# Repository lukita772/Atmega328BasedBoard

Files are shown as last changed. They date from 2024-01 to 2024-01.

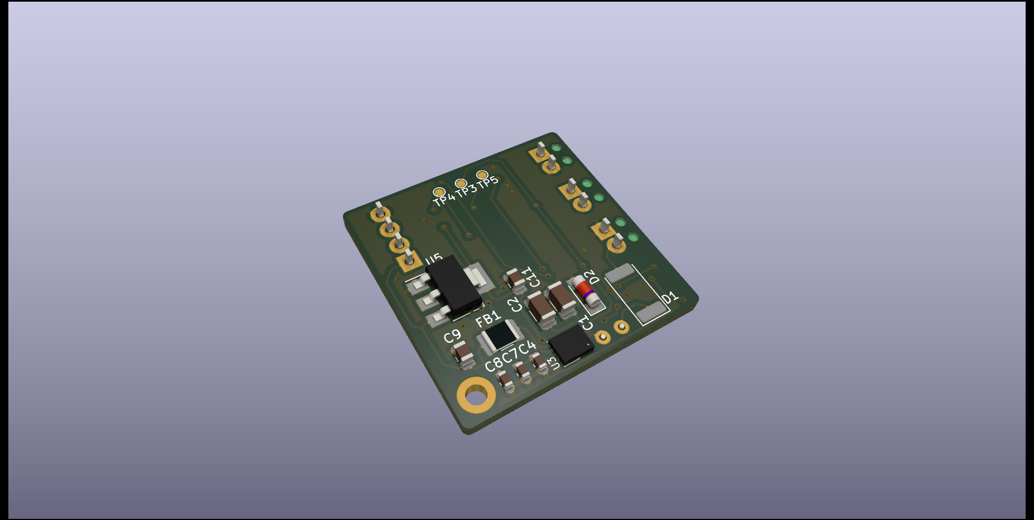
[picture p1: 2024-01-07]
Schematics&Renders/Hibot_agostiniLuca_boardBack.png

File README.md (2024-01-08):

# Atmega328BasedBoard
Hibot_agostiniLuca_boardFront
Hibot_agostiniLuca_boardBack
[Schematic.pdf](https://github.com/lukita772/Atmega328BasedBoard/files/13856203/Schematic.pdf)

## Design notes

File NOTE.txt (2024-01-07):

For time reasons, i couldnt finish to choose the calculus for the right protections in the input circuit

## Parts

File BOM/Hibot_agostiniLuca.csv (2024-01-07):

Id | Designator | Package | Quantity | Designation | Supplier and ref
1 | U6 | TRANS_IRL100HS121 | 1 | IRLHS6342TRPBF
2 | R7,R4,R8,R5 | R_0603_1608Metric | 4 | 5k 5%
3 | R2 | R_0603_1608Metric | 1 | 1Meg 1%
4 | F1 | C_Disc_D3.0mm_W1.6mm_P2.50mm | 1 | Polyfuse_Small
5 | R3 | R_0603_1608Metric | 1 | 10k 5%
6 | U2 | LGA-12_2x2mm_P0.5mm | 1 | LSM303C
7 | R6 | R_0603_1608Metric | 1 | 200m 1%
8 | C10 | C_0805_2012Metric | 1 | 10u 16v X7R
9 | L1 | L_0201_0603Metric | 1 | 10uH
10 | Y1 | Crystal_SMD_Abracon_ABM10-4Pin_2.5x2.0mm | 1 | RH100-8.000-8-2020-TR
11 | C14,C13 | C_0603_1608Metric | 2 | 22pF 16v X7R
12 | C3 | C_0805_2012Metric | 1 | 220nF 16v X7R
13 | J3 | TerminalBlock_Phoenix_MPT-0,5-2-2.54_1x02_P2.54mm_Horizontal | 1 | Load
14 | J2 | TerminalBlock_Phoenix_MPT-0,5-4-2.54_1x04_P2.54mm_Horizontal | 1 | SerialOutput
15 | D3 | D_0805_2012Metric | 1 | 1N4007FL
16 | R1 | R_0603_1608Metric | 1 | 1k 5%
17 | J4 | TerminalBlock_Phoenix_MPT-0,5-2-2.54_1x02_P2.54mm_Horizontal | 1 | Output2
18 | U4 | QFN-32-1EP_5x5mm_P0.5mm_EP3.1x3.1mm | 1 | ATmega328-M
19 | J1 | TerminalBlock_Phoenix_MPT-0,5-2-2.54_1x02_P2.54mm_Horizontal | 1 | Input
20 | U1 | SOT-23-5 | 1 | 24LC32AT-I/OT
21 | C6,C5 | C_0603_1608Metric | 2 | 100nF 16v X7R
22 | SW1 | SW_SPST_B3U-1000P | 1 | RST
23 | Q2,Q1 | SOT-23 | 2 | BSS138
24 | H1 | MountingHole_2.2mm_M2_DIN965_Pad | 1 | MountingHole
25 | C12 | C_0805_2012Metric | 1 | 100nF 16v X7R
26 | TP3 | TestPoint_Pad_D1.0mm | 1 | Test_VCC
27 | D1 | D_2512_6332Metric | 1 | VSSC8L45-M3
28 | C8,C7 | C_0603_1608Metric | 2 | 22nF 16v X7R
29 | U5 | SOT-223-3_TabPin2 | 1 | AMS1117-1.8
30 | FB1 | R_1210_3225Metric_Pad1.30x2.65mm_HandSolder | 1 | BLE32PN300SN1L
31 | C2,C1 | C_1206_3216Metric | 2 | 4.7uF 50v X5R
32 | C4 | C_0603_1608Metric | 1 | 22uF 16v X7R
33 | D2 | D_MiniMELF | 1 | BZV55B24
34 | TP5 | TestPoint_Pad_D1.0mm | 1 | Test_1.8v
35 | C11 | C_0805_2012Metric | 1 | 22uF 6.3v X7R
36 | TP4 | TestPoint_Pad_D1.0mm | 1 | Test_5v
37 | U3 | Texas_SIL0010A_MicroSiP-10-1EP_3.8x3mm_P0.6mm_EP0.7x2.9mm_ThermalVias | 1 | LMZM23600V3
38 | C9 | C_0805_2012Metric | 1 | 10uF 16v X7R

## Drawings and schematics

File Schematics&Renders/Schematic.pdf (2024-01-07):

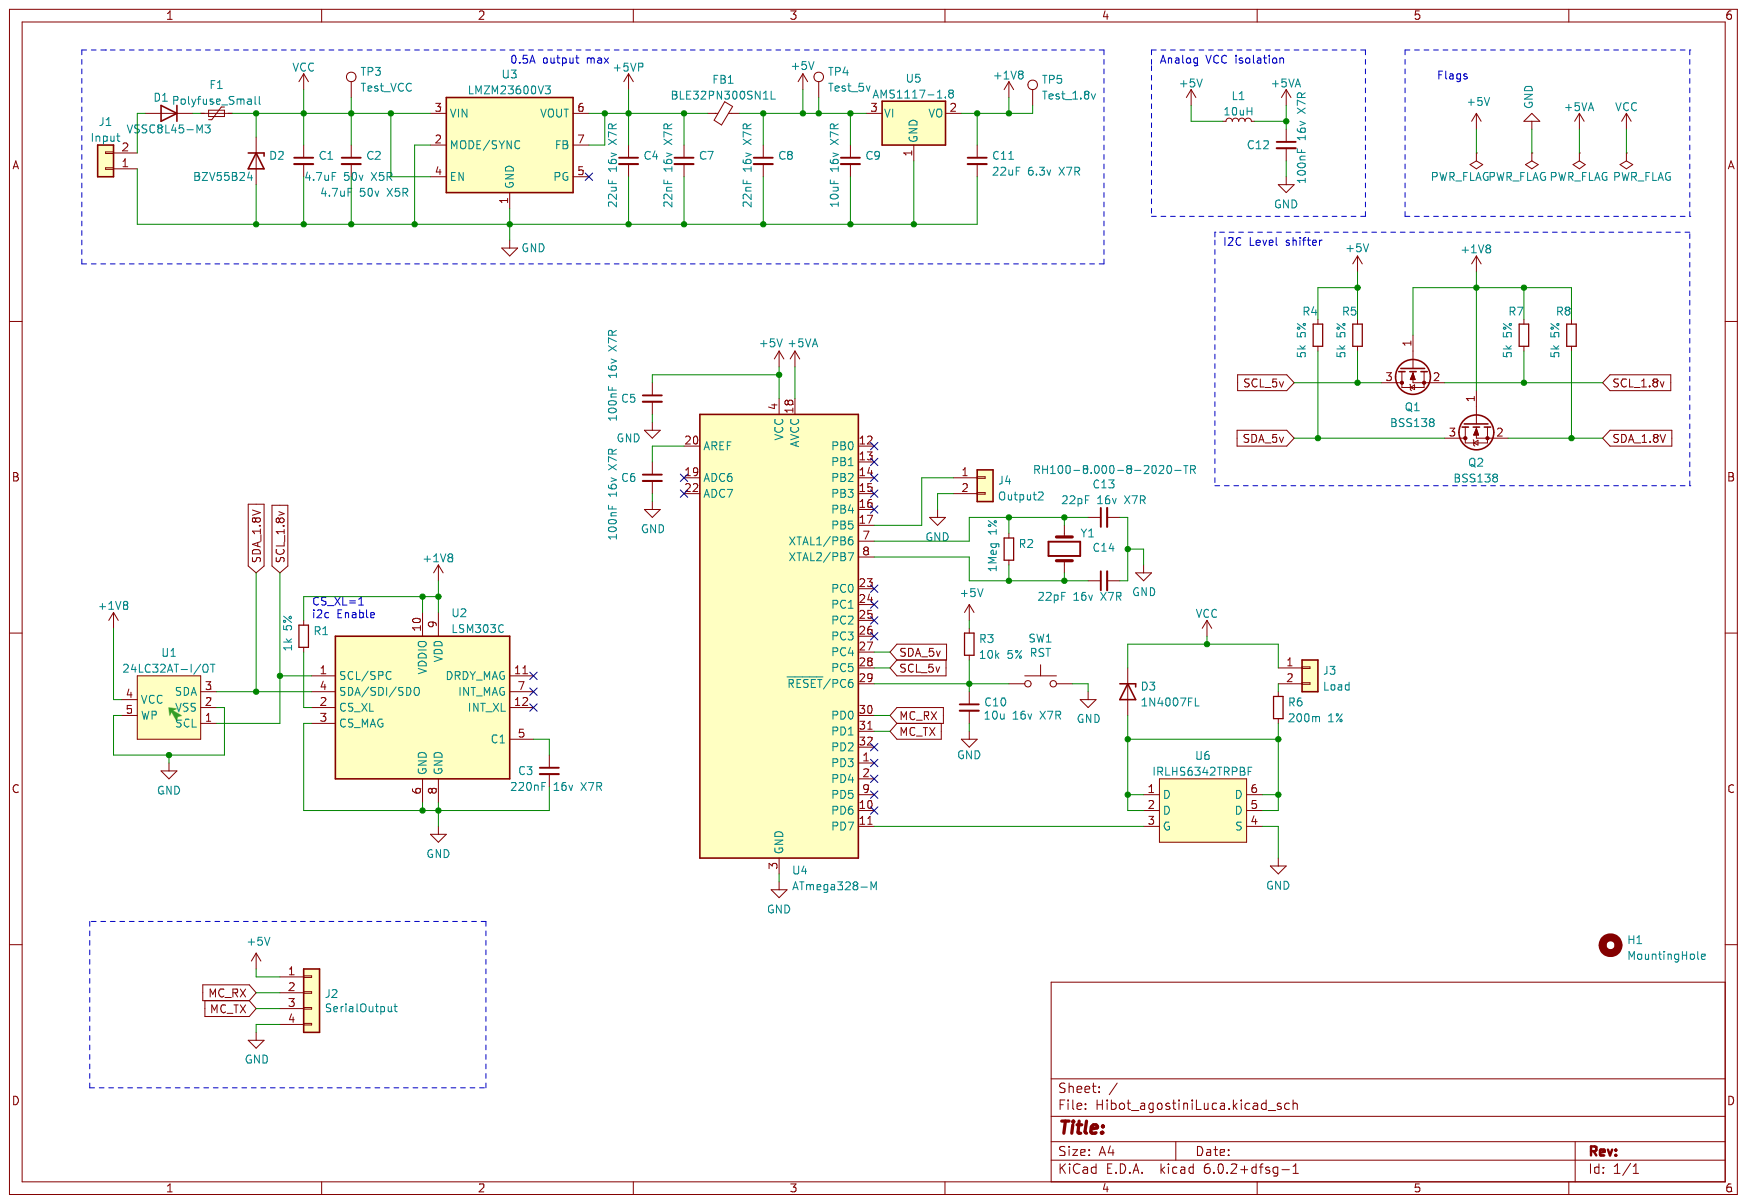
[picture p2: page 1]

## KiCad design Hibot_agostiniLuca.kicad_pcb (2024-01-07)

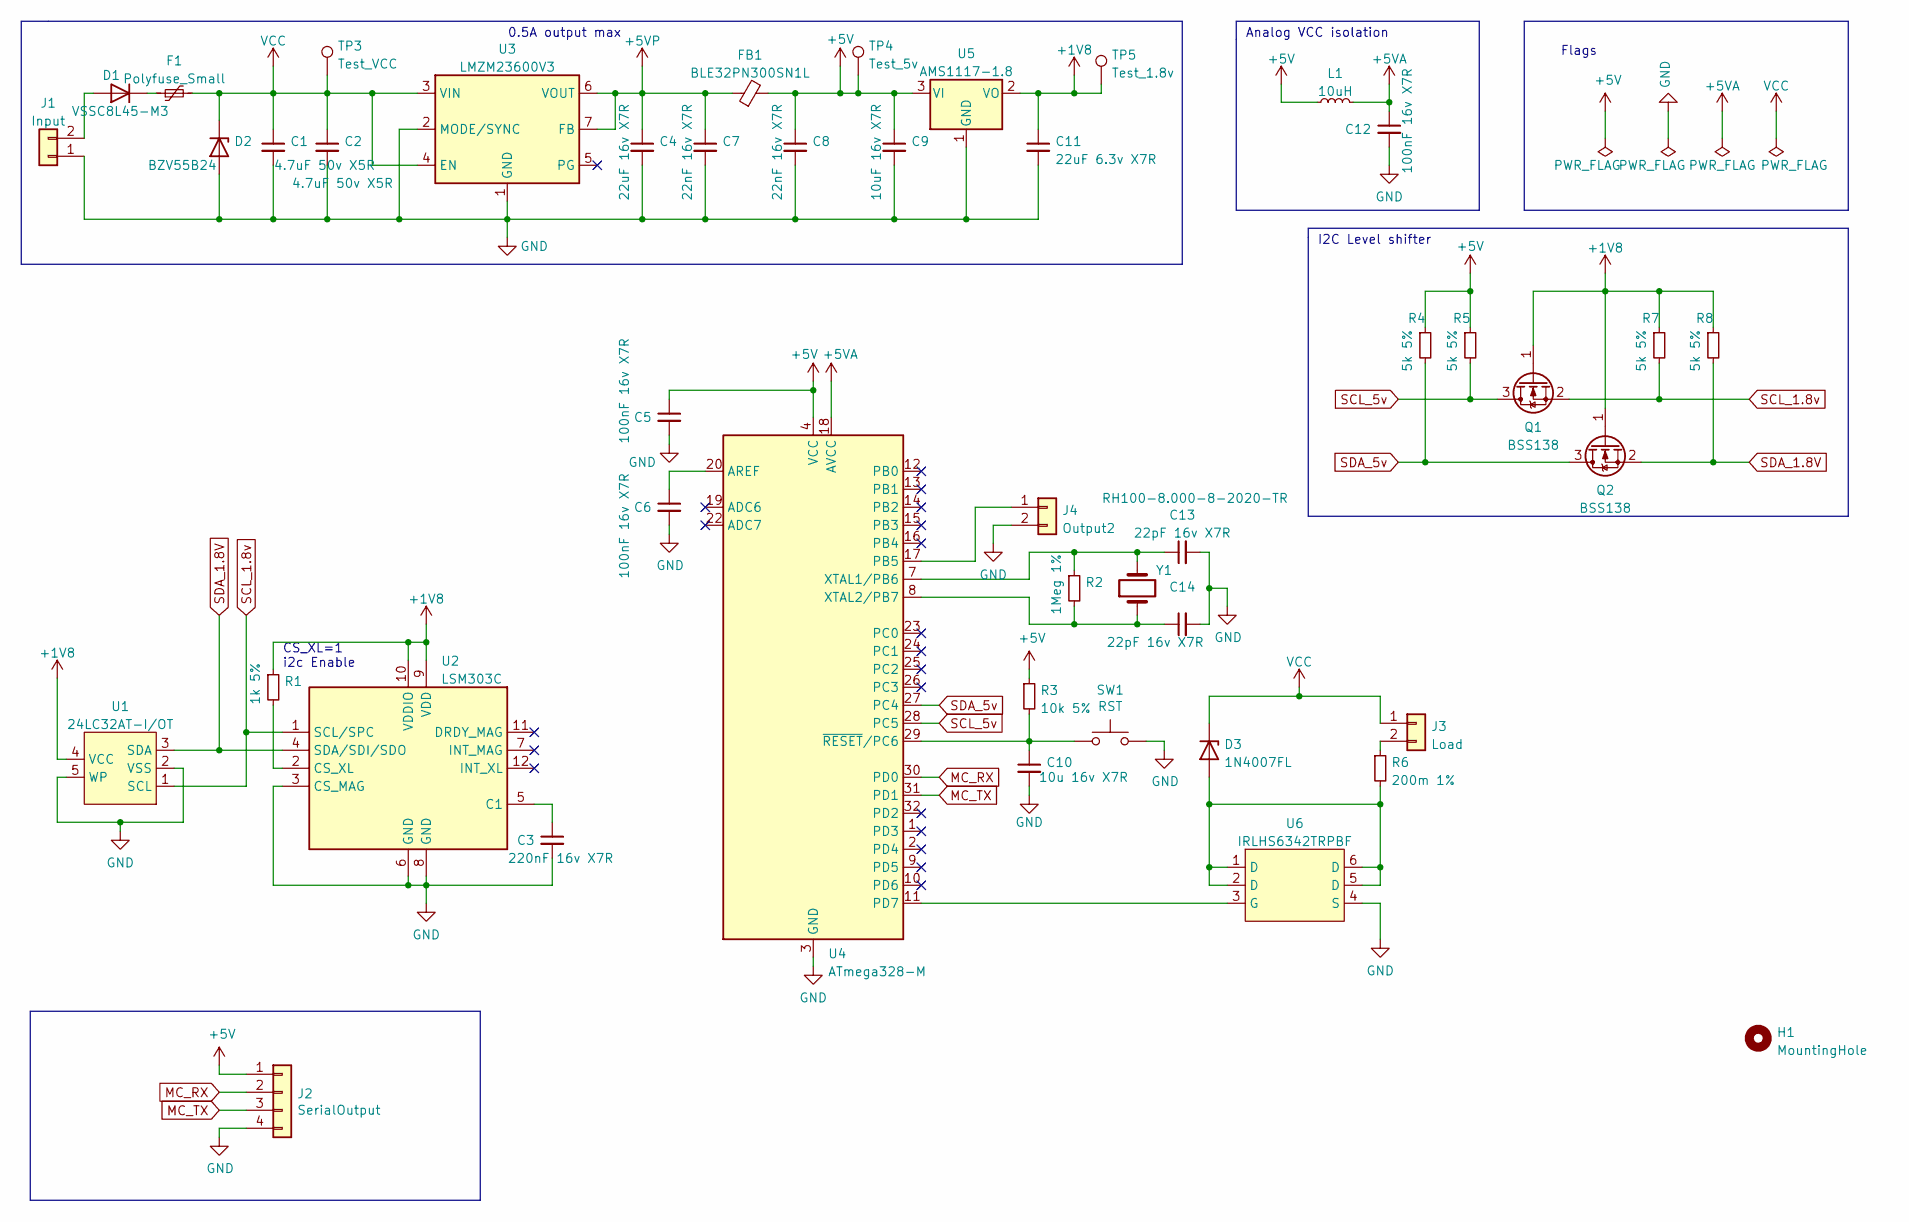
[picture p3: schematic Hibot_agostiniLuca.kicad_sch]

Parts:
C1, C2: 4.7uF 50v X5R; C_1206_3216Metric
C3: 220nF 16v X7R; C_0805_2012Metric
C4: 22uF 16v X7R; C_0603_1608Metric
C5, C6: 100nF 16v X7R; C_0603_1608Metric
C7, C8: 22nF 16v X7R; C_0603_1608Metric
C9: 10uF 16v X7R; C_0805_2012Metric
C10: 10u 16v X7R; C_0805_2012Metric
C11: 22uF 6.3v X7R; C_0805_2012Metric
C12: 100nF 16v X7R; C_0805_2012Metric
C13, C14: 22pF 16v X7R; C_0603_1608Metric
D1: VSSC8L45-M3; D_2512_6332Metric
D2: BZV55B24; D_MiniMELF
D3: 1N4007FL; D_0805_2012Metric
F1: Polyfuse_Small; C_Disc_D3.0mm_W1.6mm_P2.50mm
FB1: BLE32PN300SN1L; R_1210_3225Metric_Pad1.30x2.65mm_HandSolder
H1: MountingHole; MountingHole_2.2mm_M2_DIN965_Pad
J1: Input; TerminalBlock_Phoenix_MPT-0,5-2-2.54_1x02_P2.54mm_Horizontal
J2: SerialOutput; TerminalBlock_Phoenix_MPT-0,5-4-2.54_1x04_P2.54mm_Horizontal
J3: Load; TerminalBlock_Phoenix_MPT-0,5-2-2.54_1x02_P2.54mm_Horizontal
J4: Output2; TerminalBlock_Phoenix_MPT-0,5-2-2.54_1x02_P2.54mm_Horizontal
L1: 10uH; L_0201_0603Metric
Q1, Q2: BSS138; SOT-23
R1: 1k 5%; R_0603_1608Metric
R2: 1Meg 1%; R_0603_1608Metric
R3: 10k 5%; R_0603_1608Metric
R4, R5, R7, R8: 5k 5%; R_0603_1608Metric
R6: 200m 1%; R_0603_1608Metric
SW1: RST; SW_SPST_B3U-1000P
TP3: Test_VCC; TestPoint_Pad_D1.0mm
TP4: Test_5v; TestPoint_Pad_D1.0mm
TP5: Test_1.8v; TestPoint_Pad_D1.0mm
U1: 24LC32AT-I/OT; SOT-23-5
U2: LSM303C; LGA-12_2x2mm_P0.5mm
U3: LMZM23600V3; Texas_SIL0010A_MicroSiP-10-1EP_3.8x3mm_P0.6mm_EP0.7x2.9mm_T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
U4: ATmega328-M; QFN-32-1EP_5x5mm_P0.5mm_EP3.1x3.1mm
U5: AMS1117-1.8; SOT-223-3_TabPin2
U6: IRLHS6342TRPBF; TRANS_IRL100HS121
Y1: RH100-8.000-8-2020-TR; Crystal_SMD_Abracon_ABM10-4Pin_2.5x2.0mm

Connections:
+1V8: C11.1, Q1.1 (G), Q2.1 (G), R1.1, R7.1, R8.1, TP5.1, U1.4 (VCC), U2.9 (VDD), U2.10 (VDDIO), U5.2 (VO)
+5V: C5.1, C8.1, C9.1, FB1.2, J2.1, L1.1, R3.1, R4.1, R5.1, TP4.1, U4.4 (VCC), U4.6 (VCC), U5.3 (VI)
+5VA: C12.1, L1.2, U4.18 (AVCC)
+5VP: C4.1, C7.1, FB1.1, U3.6 (VOUT), U3.7 (FB)
GND: C1.2, C2.2, C3.2, C4.2, C5.2, C6.2, C7.2, C8.2, C9.2, C10.2, C11.2, C12.2, C13.2, C14.2, D2.2 (A), J1.1, J2.4, J4.2, SW1.2, U1.2 (VSS), U1.5 (WP), U2.3 (CS_MAG), U2.6 (GND), U2.8 (GND), U3.1 (GND), U3.2 (MODE/SYNC), U3.11 (GND), U4.3 (GND), U4.5 (GND), U4.21 (GND), U4.33 (GND), U5.1 (GND), U6.4 (S)
MC_RX: J2.2, U4.30 (PD0)
MC_TX: J2.3, U4.31 (PD1)
unnamed: C3.1, U2.5 (C1)
unnamed: C6.1, U4.20 (AREF)
unnamed: C10.1, R3.2, SW1.1, U4.29 (~RESET/PC6)
unnamed: C13.1, R2.1, U4.7 (XTAL1/PB6), Y1.2
unnamed: C14.1, R2.2, U4.8 (XTAL2/PB7), Y1.1
unnamed: D1.1 (K), F1.1
unnamed: D1.2 (A), J1.2
unnamed: D3.2 (A), R6.2, U6.1 (D), U6.2 (D), U6.5 (D), U6.6 (D)
unnamed: J3.2, R6.1
unnamed: J4.1, U4.17 (PB5)
unnamed: R1.2, U2.2 (CS_XL)
unnamed: U4.11 (PD7), U6.3 (G)
SCL_1.8v: Q1.2 (S), R7.2, U1.1 (SCL), U2.1 (SCL/SPC)
SCL_5v: Q1.3 (D), R5.2, U4.28 (PC5)
SDA_1.8V: Q2.2 (S), R8.2, U1.3 (SDA), U2.4 (SDA/SDI/SDO)
SDA_5v: Q2.3 (D), R4.2, U4.27 (PC4)
VCC: C1.1, C2.1, D2.1 (K), D3.1 (K), F1.2, J3.1, TP3.1, U3.3 (VIN), U3.4 (EN)

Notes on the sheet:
Analog VCC isolation
CS_XL=1 i2c Enable
0.5A output max
I2C Level shifter
Flags

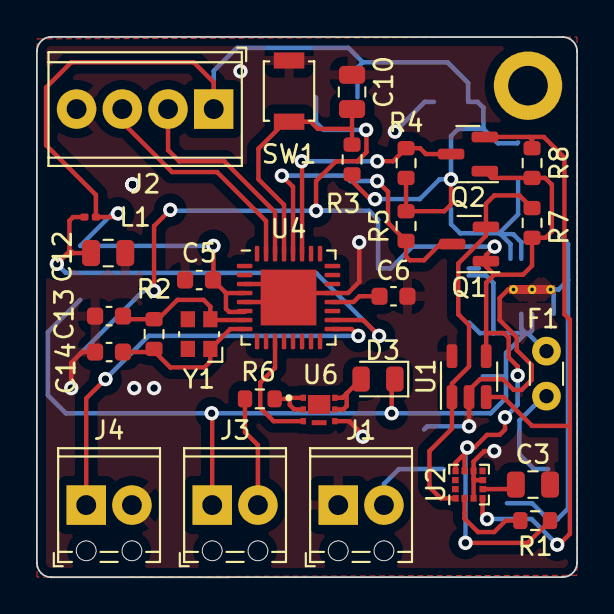
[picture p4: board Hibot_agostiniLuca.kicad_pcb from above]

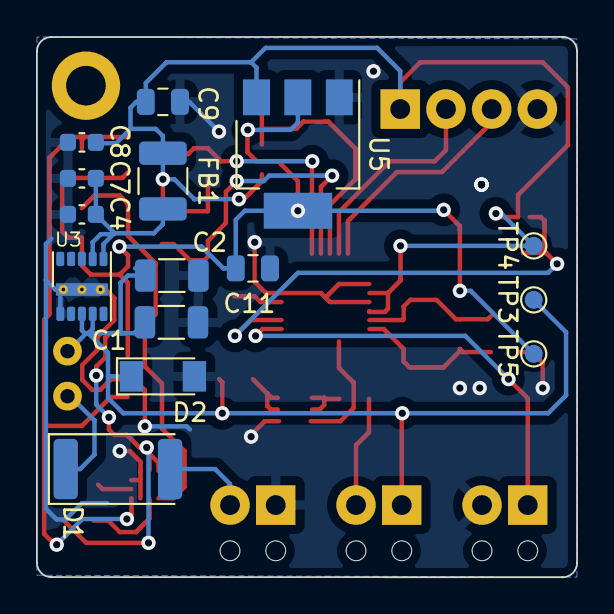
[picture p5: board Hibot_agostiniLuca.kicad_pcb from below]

Board: 2 copper layers, 30.0 x 30.0 mm, 46 parts (15 on the bottom side), 24 nets.
